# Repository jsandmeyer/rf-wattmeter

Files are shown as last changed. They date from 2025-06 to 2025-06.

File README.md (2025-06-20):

## Wattmeter

Based on AK3Y's wattmeter published in QSL magazine.

See license in `main.cpp` for code.  Some other files (like the font) are licensed separately.

### Differences from previous designs
1. Built to run upside-down (heatsink up)
2. Changed to use a Pi Pico 2 to reduce BOM cost
3. Added some built-in standoffs to case
4. Added new holes for USB, and for optional PowerPoles
5. Changed dimensions of PCB and drill/tap locations for heatsink
6. Used 128x64 OLED from AliExpress which did not match datasheet / original dimensions at all
7. Changed microstrip width based on recommendation from calculator
8. I used connectors for everything, but you could just solder the wires in
9. Changed other dimensions of case cutouts
10. Used mostly different parts from original design

### Printing
Try to orient the parts so the smooth side faces out.
1. Print bottom shell normally.
2. The top shell should be rotated 180 degrees for better printing.
3. Front and back panels should be oriented so the "outside" of each plate faces the build plate for a smooth finish.

### Assembly

#### Parts Required

| ID | Description | QTY | Optional QTY |
|---|---|-----|---|
| PCB1 | RF PCB | 1 | |
| PCB2 | Pico PCB | 1 | |
| A1 | Raspberry Pi Pico 2 | 1 | |
| A2 | SSD1306 128x64 I2C OLED | 1 | |
| C1 | 10nF 1206 Cer. Cap. | 1 | |
| C2 | 1nF 1206 Cer. Cap. | 1 | |
| C3 | 10uF 35V 5mm Elec. Cap. | | 1 |
| C4 | 47uF 35V 5mm Elec. Cap. | | 1 |
| D1-2a,b | TMMBAT41FILM 100V Diode | 3 | |
| D3 | PBZTBR13.0B Zener Diode | 1 | |
| D4 | 1N5819 | | 1 |
| HS1 | 60x45x18mm heatsink | 1 | |
| J1 | SMA board-edge connector | 1 | |
| J2 | JST-XA BM02B-XASS-TF | 1 | |
| J3-4 | JST-XA B02B-XASK-1 | 1 | 1 |
| J5 | 1x4 2.54mm Breakaway Hdr. | 1 | |
| R1 | RFR 50-250 Flange Resistor | 1 | |
| R2 | 100K 1206 Resistor | 1 | |
| R3 | 3K 1206 Resistor | 1 | |
| R4 | DNP | | |
| TH1 | DNP | | |
| U1 | UA7805 | | 1 |
| VR1 | 100K PT10WV05-104A2020-3-NE-S | 1 | |

#### Cable Assemblies
Cable assemblies assume Pin 1 of a connector is the RIGHTMOST contact if you are looking at the connector's contact end, with the latch facing UP.
Cut wires to the length indicated, then strip and crimp them.

1. 5" Inter-PCB Wire
   1. JST-XA connectors
   2. RF PCB side: Pin 1 is red, Pin 2 is black
   3. Pico PCB side: Pin 1 is black, Pin 2 is red
   4. Pins 1 and 2 are reversed on either board
2. 2.5" PowerPole Wire (optional)
   1. JST-XA connector and PowerPole connector
   2. Pico PCB side: Pin 1 is red, Pin 2 is black
3. 3.5" OLED Wire (DuPont/Molex)
   1. Connectors are symmetrical
   2. Try to use a marked or black conductor for GND

#### Tools Needed
1. Crimping tool for JST & DuPont connectors
2. Crimping tool for PowerPole connectors
3. Drill bits and taps for M2 and M3 screw holes
4. Wire cutters, strippers, pliers
5. Metric allen key / screwdriver / wrench / socket for M2/3 screws and nuts
6. Soldering iron with solder, flux, and solder-wick
7. 3D printer if printing your own case

#### Steps
1. Assemble the heatsink, RF PCB, and flange resistor prior to soldering anything.
   1. Use 4x 6mm M3 screws to hold the PCB to the heatsink
   2. Use 2x 6mm M2 screws to hold the flange resistor to the heatsink
   3. Make sure the flange resistor tab rests on/above the PCB pad for it
2. Soldering the RF PCB
   1. Use flux liberally
   2. The pads for diodes were designed for larger diodes, but many will fit fine
3. Soldering the Pico PCB
   1. Parts U1, C3, C4, D4, and J4 may be omitted if you do not want an external power supply other than USB
   2. D4 is a very tight fit
   3. Use flux to help solder the Pico 2
   4. R4 and Thermistor are optional in case you want to have a Thermistor (you will need to code this in)
4. Installing the PCBs
   1. Insert 4x 8mm M3 screws into the screw holes on the "top" shell from the outside
   2. Place the RF PCB into the "top" shell with the heatsink going through the big hole, and the SMA adapter through the small side hole, aligned with the M3 screws
   3. Attach 4x 15mm~6mm M3 hex standoffs (female side) to the M3 screws to hold the RF PCB down
   4. Attach one end of the inter-PCB wire to the RF PCB
   5. Place the Pico PCB onto the M3 hex standoffs (male side) so that the potentiometer and BOOTSEL button align to the holes when the "bottom" shell is placed onto the "top" shell
   6. Use 4x M3 lock nuts to hold the Pico PCB to the M3 standoffs
   7. Attach the other end of the inter-PCB wire to the Pico PCB
5. Assembling the OLED panel
   1. Mark on the top edge of the OLED panel above the GND pin
   2. Use 4x 8mm M2 screws and M2 lock nuts to hold the OLED display in place on the front panel - be gentle with the PCB
   3. Place the OLED display panel so the connector is above the Pico PCB
   4. Attach the OLED wire between the display and the PCB
6. Assembling the Power/USB panel
   1. Install the PowerPole connector
   2. File the hole for the PowerPole connector if needed
   3. Use glue to secure the PowerPole connector if desired
   4. Place the Power/USB panel so the PowerPole connector is above the Pico PCB
   5. Attach the PowerPole wire to the PCB
7. Assemble the top of the case
   1. Place the "bottom" shell on the assembly
   2. Affix with 4x 6mm M2 screws

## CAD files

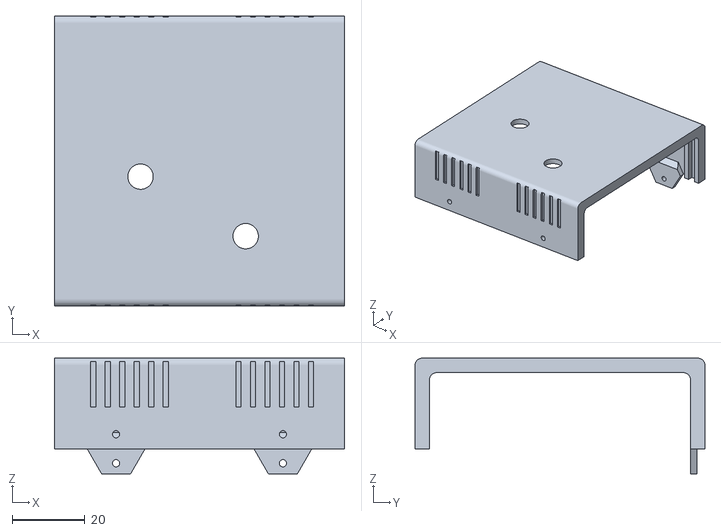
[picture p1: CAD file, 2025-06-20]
stl/TopShell-Mod.stl
80.0 x 80.0 x 31.9

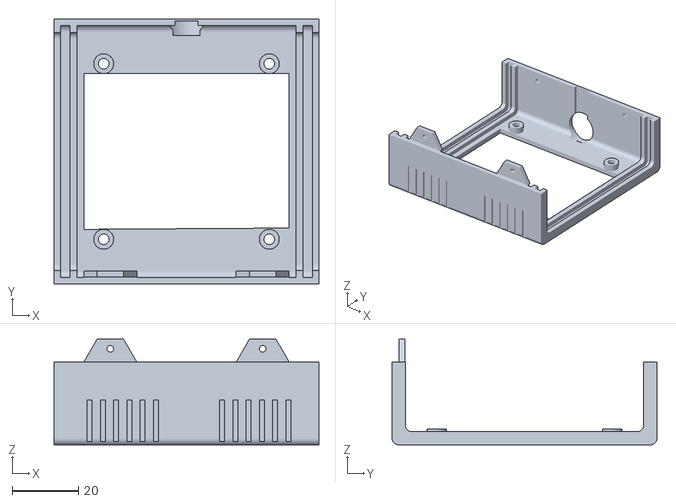
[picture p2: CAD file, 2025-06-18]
stl/BottomShell-Mod.stl
80.0 x 80.0 x 31.9

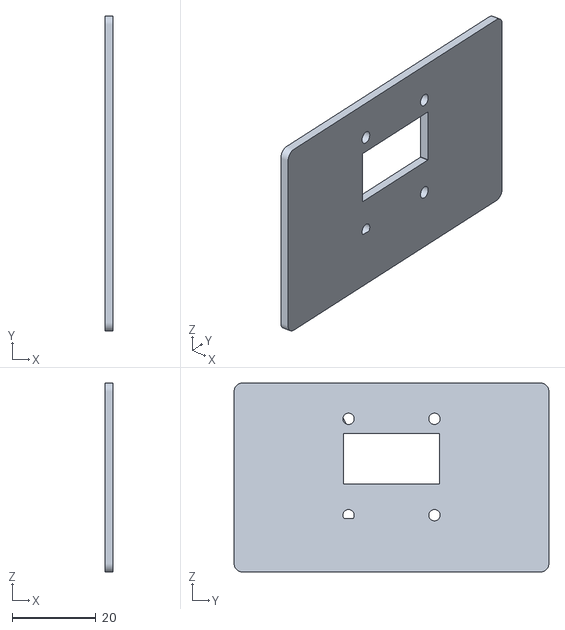
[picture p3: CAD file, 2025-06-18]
stl/FrontPanel-Mod.stl
2.00 x 75.1 x 45.1

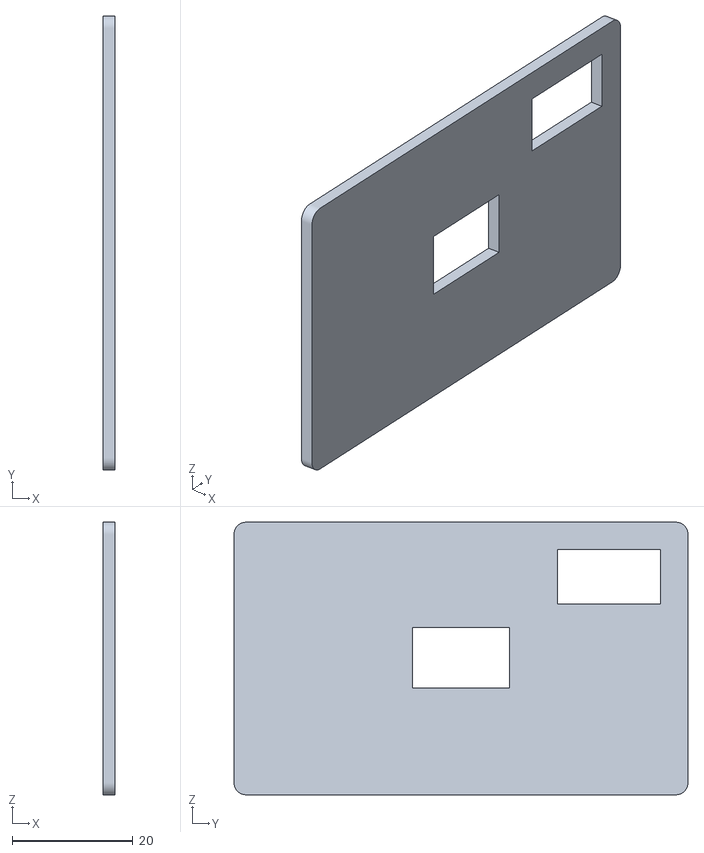
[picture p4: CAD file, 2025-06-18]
stl/BackPanel-Mod.stl
2.00 x 75.1 x 45.1

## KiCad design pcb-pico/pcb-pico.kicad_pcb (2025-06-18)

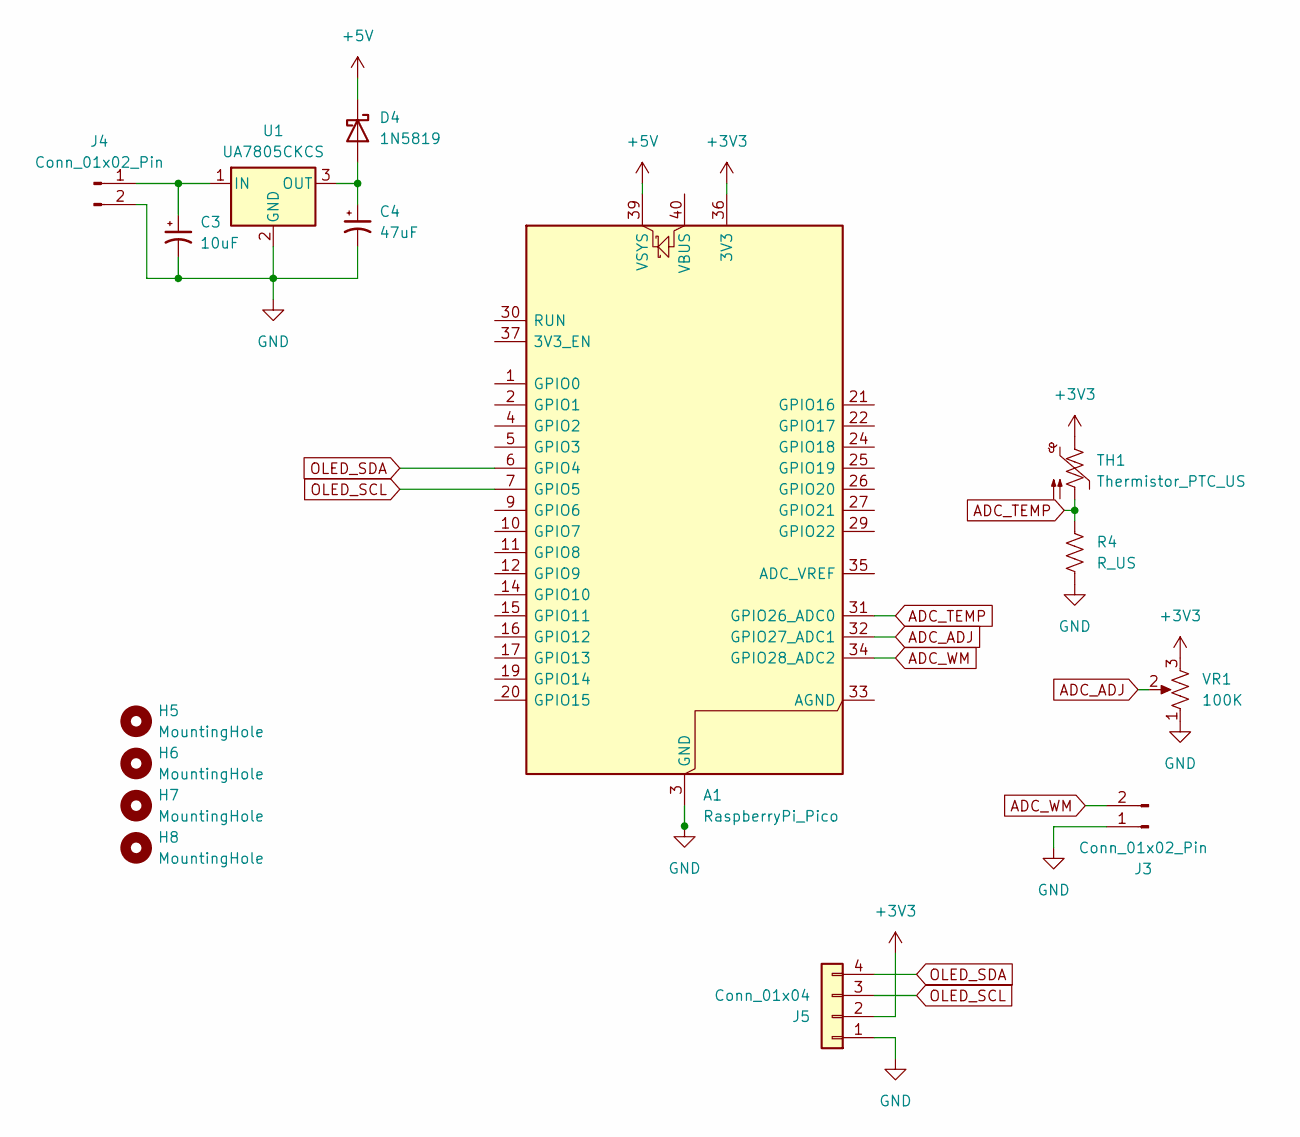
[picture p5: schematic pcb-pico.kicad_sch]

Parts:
A1: RaspberryPi_Pico; RaspberryPi_Pico_Common_Unspecified
C3: 10uF; CP_Radial_D5.0mm_P2.00mm
C4: 47uF; CP_Radial_D5.0mm_P2.00mm
D4: 1N5819; D_DO-34_SOD68_P7.62mm_Horizontal
H5, H6, H7, H8: MountingHole; MountingHole_3.2mm_M3
J3, J4: Conn_01x02_Pin; JST_XA_B02B-XASK-1-A_1x02_P2.50mm_Vertical
J5: Conn_01x04; PinHeader_1x04_P2.54mm_Vertical
R4: R_US; R_Axial_DIN0207_L6.3mm_D2.5mm_P10.16mm_Horizontal
TH1: Thermistor_PTC_US; PinHeader_1x02_P2.54mm_Vertical
U1: UA7805CKCS; TO-220-3_Vertical
VR1: 100K; Potentiometer_Piher_PT-10-V05_Vertical

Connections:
+3V3: A1.36 (3V3), J5.2, TH1.1, VR1.3
+5V: A1.39 (VSYS), D4.1 (K)
ADC_ADJ: A1.32 (GPIO27_ADC1), VR1.2
ADC_TEMP: A1.31 (GPIO26_ADC0), R4.1, TH1.2
ADC_WM: A1.34 (GPIO28_ADC2), J3.2
GND: A1.3 (GND), A1.8 (GND), A1.13 (GND), A1.18 (GND), A1.23 (GND), A1.28 (GND), A1.38 (GND), C3.2, C4.2, J3.1, J4.2, J5.1, R4.2, U1.2 (GND), VR1.1
unnamed: C4.1, D4.2 (A), U1.3 (OUT)
unnamed: C3.1, J4.1, U1.1 (IN)
OLED_SCL: A1.7 (GPIO5), J5.3
OLED_SDA: A1.6 (GPIO4), J5.4

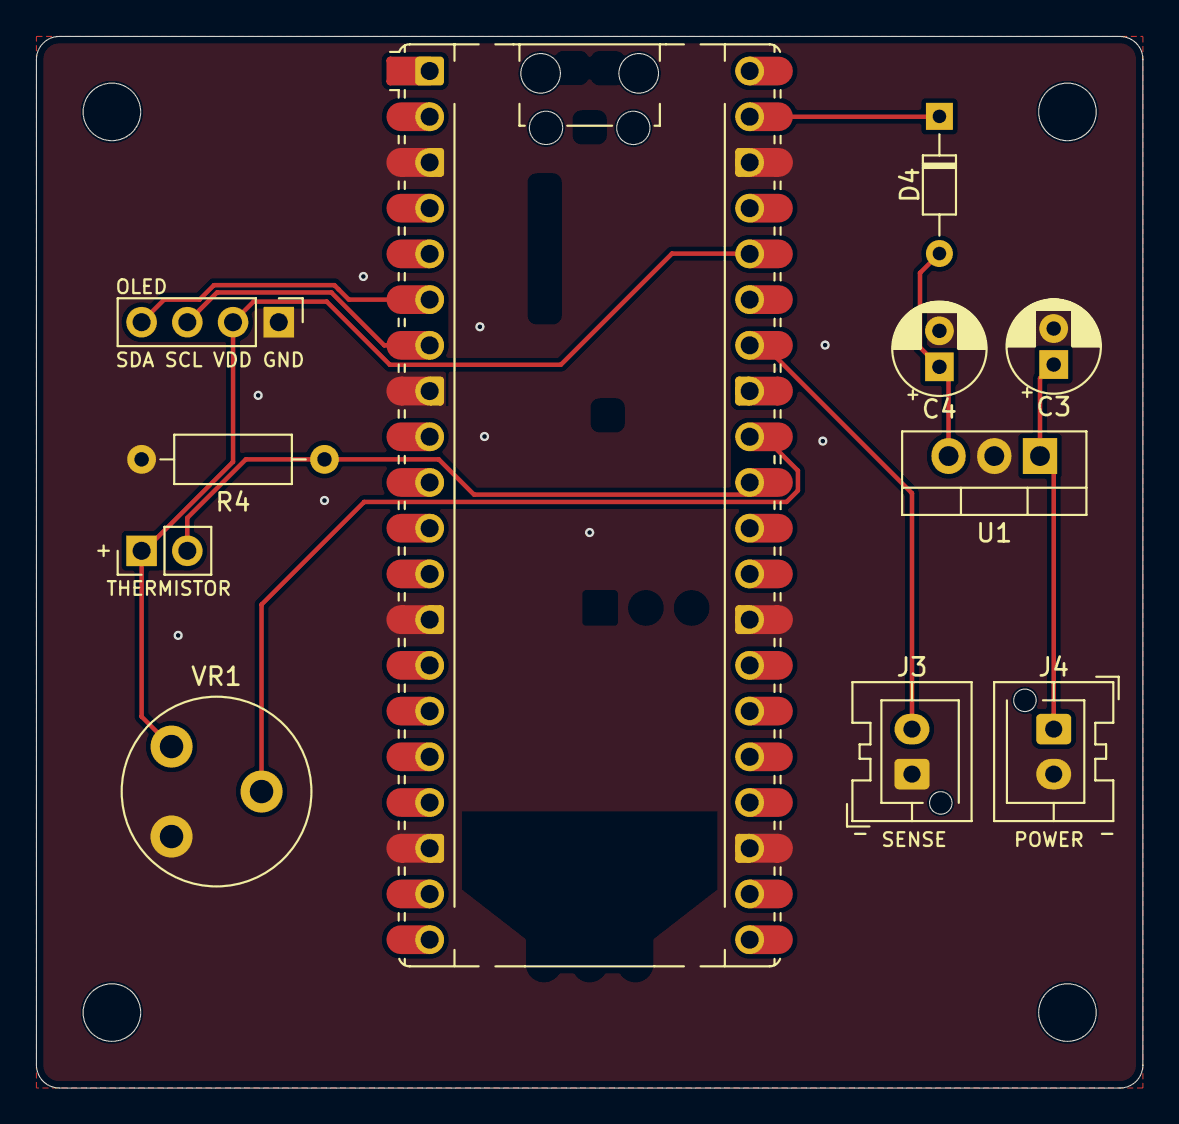
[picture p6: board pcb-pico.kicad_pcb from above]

Board: 2 copper layers, 61.5 x 58.4 mm, 15 parts (0 on the bottom side), 10 nets.

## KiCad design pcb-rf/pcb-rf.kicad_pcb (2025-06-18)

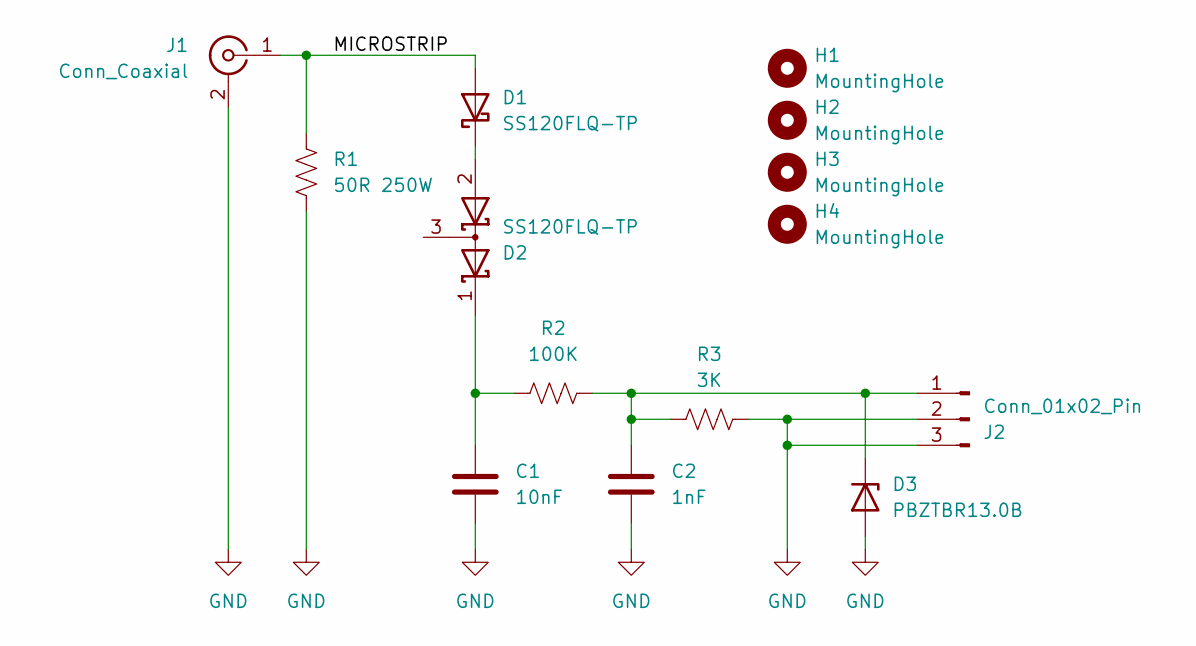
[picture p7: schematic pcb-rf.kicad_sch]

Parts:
C1: 10nF; C_1206_3216Metric_Pad1.33x1.80mm_HandSolder
C2: 1nF; C_1206_3216Metric_Pad1.33x1.80mm_HandSolder
D1: SS120FLQ-TP; Vishay_SlimSMA_HV_DO-221AC_HandSolder
D2: SS120FLQ-TP; Vishay_SlimSMA_HV_DO-221AC_HandSolder_SQ
D3: PBZTBR13.0B; D_SMB_Handsoldering
H1, H2, H3, H4: MountingHole; MountingHole_3.2mm_M3
J1: Conn_Coaxial; SMA_Custom_EdgeMount
J2: Conn_01x02_Pin; CONN_BM02B-XASS-TFLFSN_JST
R1: 50R 250W; FlangeResistor
R2: 100K; R_1206_3216Metric_Pad1.30x1.75mm_HandSolder
R3: 3K; R_1206_3216Metric_Pad1.30x1.75mm_HandSolder

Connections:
/MICROSTRIP: D1.2 (A), J1.1 (In), R1.1
GND: C1.2, C2.2, D3.2 (A), J1.2 (Ext), J2.2, J2.3, R1.2, R3.1
unnamed: D1.1 (K), D2.2 (A)
unnamed: C1.1, D2.1 (K), R2.2
unnamed: C2.1, D3.1 (K), J2.1, R2.1, R3.2

Board: 2 copper layers, 14 parts (0 on the bottom side), 5 nets, no tracks yet.

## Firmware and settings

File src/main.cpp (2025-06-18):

/*
=== Raspberry Pi Versions ==============================================================================================

    Release PI1.00  June 28, 2025, John Sandmeyer, AI7YR
                    [Work In Progress]
                    Update to deploy to a less expensive Pi Pico 2 (RP2350) via PlatformIO
                    Uses both cores (Core0 for measuring, Core1 for rendering)
                    Trust Pi Pico ADC range due to lack of good external reference
                    Later: recalculate resistor divider calculation to account for Pi Pico 2

=== Arduino Versions ===================================================================================================

    Release 1.02    February 23, 2024, Bob Fontana, AK3Y
                    Overhaul of display code using display.width and strlen
                    Corrected power calculation code in 2017 W8TEE article
                    Added 3.3V reference adjustment to determine true ADC range
                    Modified resistor divider calculation to provide more accurate measurement

    Release 1.01    June 15, 2018, Jack Purdum, W8TEE. Minor edits to the code to make it easier to read

    Release 1.0     Oct.13, 2017, Jack Purdum, W8TEE, Al Peter, AC8GY. You may use/modify this code,
                    but keep this comment intact in the file and place any changes in front of this
                    entry.
*/

#include <RP2350Wrapper.h> // must include first to avoid warnings
#include <Adafruit_GFX.h>
#include <Adafruit_SSD1306.h>
#include <SerialUSB.h>
#include <can2040.h>
#include <pico/util/queue.h>
#include <Debug.h>

#include "Core0.h"
#include "Core1.h"

#define RP_I2C_USE_I2C0 TRUE

constexpr auto SER_BAUD = 115200UL;

static queue_t wattageQueue;

Adafruit_SSD1306 *display;
Core0 *core0;
Core1 *core1;

void setup() {
    DEBUG(Serial.begin(SER_BAUD));
    DEBUG(Serial.print("Starting core0\n"));

    queue_init(&wattageQueue, sizeof(CAN2040::Message), 128);

    rp2040.fifo.push_nb(0xFFFF);
    DEBUG(Serial.print("Core0 init fifo sent\n"));

    core0 = new Core0(&wattageQueue);
}

void setup1() {
    DEBUG(Serial.print("Starting core1\n"));

    // wait for ready message
    while (rp2040.fifo.pop() != 0xFFFF) {
        tight_loop_contents();
    }

    DEBUG(Serial.print("Core1 init fifo acquired\n"));

    core1 = new Core1(&wattageQueue);
}

void loop() {
    core0->readAdjustor();
    core0->readWattage();
}

void loop1() {
    core1->renderDisplay();
}

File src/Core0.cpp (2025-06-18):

#include <SerialUSB.h>
#include <Debug.h>

#include "Core0.h"
#include "pins.h"

#define ADC_MAX                       4095      // Maximum ADC value, see analogReadResolution(12) below

#ifdef X_V33
constexpr auto V33                  = X_V33;
#else
constexpr auto V33                  = 3.255f;    // 3.3V, as measured from Pi Pico 2 (A1)
#endif

#ifdef X_R1
constexpr auto R1                   = X_R1;     // R1 as measured (dummy load resistor)
#else
constexpr auto R1                   = 49.2f;    // R1 as measured (dummy load resistor)
#endif

#ifdef X_R2
constexpr auto R2                   = X_R2;     // R2 as measured (upper divider resistor)
#else
constexpr auto R2                   = 99.39f;   // R2 as measured (upper divider resistor)
#endif

#ifdef X_R3
constexpr auto R3                   = X_R3;     // R3 as measured (lower divider resistor)
#else
constexpr auto R3                   = 2.90f;    // R3 as measured (lower divider resistor)
#endif

#ifdef X_ADC_ITERATIONS
constexpr auto ADC_ITERATIONS       = X_ADC_ITERATIONS;
#else
constexpr auto ADC_ITERATIONS       = 30;
#endif

constexpr auto DIODE_VF_SUM_H       = 1.20;     // Voltage drop from diodes (D1 + D2a + D2b) at or above 1/4
constexpr auto DIODE_VF_SUM_L2      = 0.60;     // Voltage drop from diodes (D1 + D2a + D2b) at or above 1/32
constexpr auto DIODE_VF_SUM_L1      = 0.30;     // Voltage drop from diodes (D1 + D2a + D2b) below 1/32

constexpr auto DIVIDER_RATIO        = (R2 + R3) / R3;   // Resistor divider ratio "𝛿"
constexpr auto POW_MULTIPLIER       = DIVIDER_RATIO * V33 / ADC_MAX;
constexpr auto LOAD_MULTIPLIER      = 2.0f * R1;

Core0::Core0(queue_t* wattageQueue): wattageQueue(wattageQueue) {
    DEBUG(Serial.print("Ready core0\n"));

    adjustmentValue = 0.0f;
    analogReadResolution(12);
}

/**
 * @brief Reads the value of the adjustor pin and calculates the adjustment value.
 *
 * This method reads an analog input from the defined adjustor pin (ADJ_PIN) and calculates an
 * adjustment value based on the input. The calculation scales the raw input value into a
 * defined range between a low, mid, and high value. The adjustment value is linearly interpolated
 * based on the input, where the midpoint of the input range divides scaling into two sections:
 * - For values less than or equal to the midpoint, the adjustment value is scaled between `low` and `mid`.
 * - For values greater than the midpoint, the adjustment value is scaled between `mid` and `high`.
 *
 * The computed adjustment value is stored in the `adjustmentValue` member variable.
 */
void Core0::readAdjustor() {
    const auto adjustorPinValue = static_cast<float>(analogRead(PIN_ADJUSTOR));

    constexpr auto scaleMidpoint = 1024.0f;

    constexpr auto low = 0.9f;
    constexpr auto mid = 1.0f;
    constexpr auto high = 1.1f;

    if (adjustorPinValue <= scaleMidpoint) {
        // Scale down: 0-scaleMidpoint -> low-mid
        adjustmentValue = low + (mid - low) * adjustorPinValue / scaleMidpoint;
    } else {
        // Scale up: scaleMidpoint-4095 -> mid-high
        adjustmentValue = mid + (high - mid) * ((adjustorPinValue - scaleMidpoint) / (scaleMidpoint - 1.0f));
    }
}

float Core0::getDiodeVoltageDrop(const int sensorValue) {
    if (sensorValue < 128) {
        return DIODE_VF_SUM_L1;
    }

    if (sensorValue < 1024) {
        return DIODE_VF_SUM_L2;
    }

    return DIODE_VF_SUM_H;
}

void Core0::readWattage() const {
    auto watts = 0.0f;
    auto sensorValue = 0;
    auto diodeVoltageDrop = 0.0f;

    // From AK3Y's article, use formula P_{IN} = (𝛿V_{A} + V_{D})^{2} / 2R_{LOAD}
    // Run it ADC_ITERATIONS times, then divide by that (average)
    for (auto i = 0; i < ADC_ITERATIONS; i++) {
        sensorValue = analogRead(PIN_SENSOR);

        if (sensorValue > 0) {
            diodeVoltageDrop = getDiodeVoltageDrop(sensorValue);
            watts += max(0, pow(POW_MULTIPLIER * sensorValue * adjustmentValue + diodeVoltageDrop, 2.0f) / LOAD_MULTIPLIER);
        }

        delay(10);
    }

    watts /= ADC_ITERATIONS;

    if (queue_is_full(wattageQueue)) {
        DEBUG(Serial.print("WARNING QUEUE WAS FULL\n"));
        return;
    }

    queue_try_add(wattageQueue, &watts);
    delay(50);
}
